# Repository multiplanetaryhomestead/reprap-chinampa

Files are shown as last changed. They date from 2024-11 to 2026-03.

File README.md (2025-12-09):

# RepRap Chinampa

Passive self-watering 3D-printable floating vegetable pot, inspired by the chinampa (floating garden bed).

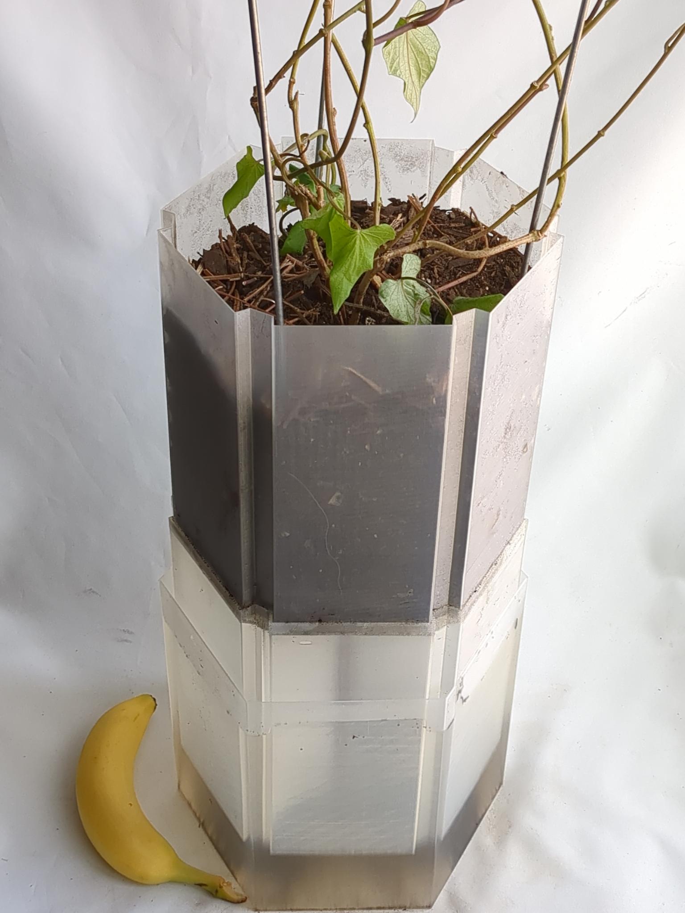
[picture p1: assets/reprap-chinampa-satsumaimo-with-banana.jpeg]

*Full scale model containing satsuma imo (Japanese sweet potato) with banana for scale*

STL files can be downloaded from the [releases](https://github.com/multiplanetaryhomestead/reprap-chinampa/releases/latest) page.

## 3D Printing Notes

### 3D Printer Filament

The models have been successfully printed in Natural PLA

### 3D Printer (Hardware) Configuration/Modifications

The models have been successfully printed on a [Prusa i3 MK3S+](https://help.prusa3d.com/product/mk3s-2) using a [hardened steel 0.4mm nozzle](https://www.printedsolid.com/products/e3d-revo-obxidian-nozzles?variant=40552237400149) and [highv part cooling duct](https://www.printables.com/model/906613-highv-part-cooling-duct-for-prusa-i3-mk3s).

**NOTE**: The standard brass nozzle is **not considered food-safe**, as it wears out. A stainless-steel or titanium nozzle is recommended if you are even considering printing with food in mind.<sup>[1](#footnote1)</sup>

### Print Profile / Slicing

**IMPORTANT**: The STL models should be sliced with **vase mode** enabled in order to produce parts that are airtight and buoyant.<sup>[2](#footnote2)</sup> We recommend slicing with [OrcaSlicer](https://github.com/SoftFever/OrcaSlicer) using the following profile. Note that the profile is for a 0.8 mm nozzle, but have been successfully tested on a 0.4 mm nozzle.

    Nozzle diameter: 0.8 mm nozzle
    Layer height: 0.15 mm
    Wall generator: Classic
    Walls printing order: Inner/Outer
    Bottom shell layers: 5
    Top fill pattern: Aligned Rectilinear
    Bottom fill pattern: Aligned Rectilinear
    Internal solid infill patter: Aligned Rectilinear
    Solid infill direction: 90 degrees
    Infill speed: 5 mm/s
    Solid infill speed: 5 mm/s
    Top solid infill speed: 5 mm/s
    First layer print speed: 5 mm/s
    Max print speed: 5 mm/s
    Overhang speed:
        10%, 25%: 5 mm/s
        25%, 50%: 5 mm/s
        50%, 75%: 5 mm/s
        75%, 100%: 5 mm/s
    Extrusion multiplier: 1.2
    Nozzle temperature:
        First layer: 220 C
        Other layers: 220 C
    Bed temperature:
        First layer: 60 C
        Other layers: 60 C
    Fan speed:
        Min: 100%
        Max: 100%
    Min print speed: 5 mm/s
    Lift height: 0.5 mm
    Retraction height: 2 mm
    Ramping lift: Enabled
    Retraction speed: 50 mm/s

**NOTE**: It is recommended that your first layer is properly calibrated, as to ensure a water-tight print.<sup>[3](#footnote3)</sup>

## Attributions

This project was inspired by the works of

- *Chinampas* pioneered by the native Aztec tribes and farmlands of southwestern region of the Valley of Mexico
- [Self-watering rectangular planter](https://www.printables.com/model/57885-self-watering-rectangular-planter-with-optional-la)
- [Avocado Boat - minimalistic](https://www.printables.com/model/179070-avocado-boat-minimalistic-vase-mode)
- [The RepRap movement](https://reprap.org/)

---
This work is licensed under a [Creative Commons Attribution-ShareAlike 4.0 International License](https://creativecommons.org/licenses/by-sa/4.0/)



<a name="footnote1">1</a>: https://help.prusa3d.com/article/food-safe-fdm-printing_112313

<a name="footnote2">2</a>: https://help.prusa3d.com/article/layers-and-perimeters_1748#spiral-vase

<a name="footnote3">3</a>: https://help.prusa3d.com/article/first-layer-calibration-i3_112364

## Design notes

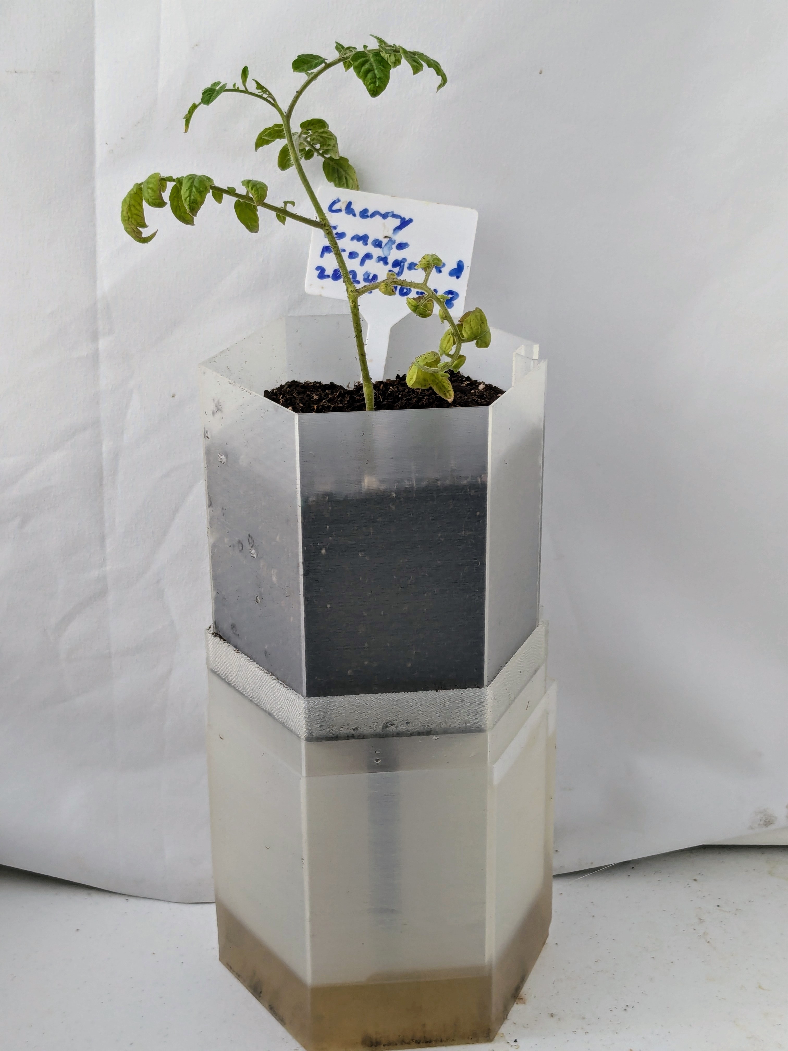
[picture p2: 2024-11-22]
assets/reprap-chinampa-half-scale.jpeg

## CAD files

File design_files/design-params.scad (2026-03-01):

// printer parameters
include <printer-params.scad>

// design parameters
scale_factor = 1.0;

t_wall = d_nozzle;
t_wall_clearance = d_nozzle;

perimeter_buffer = 10;

d_buoy = (2*y_limit/sqrt(3) - perimeter_buffer)*scale_factor;
h_buoy = z_limit*scale_factor;

d_drain_pipe = (y_limit - perimeter_buffer)*scale_factor/5;
h_drain_pipe = 140*scale_factor;

overhang_angle = 60;
d_buoy_cavity = d_buoy-4*t_wall;
h_conical_cavity = tan(90-overhang_angle)*(d_buoy_cavity/2-d_drain_pipe/2);
h_bottom_shell = 6*h_layer;

d_planter = d_buoy_cavity-2*t_wall_clearance;
d_planter_cavity = d_planter-2*t_wall;

d_water_injection_port_cavity_buoy = 20;
d_water_injection_port_buoy = d_water_injection_port_cavity_buoy + 4*t_wall;
x_water_injection_port = d_buoy/2-(d_water_injection_port_cavity_buoy/2)*sin(30)/sin(75);

d_drain_hole=3*d_nozzle;
r_drain_hole_dist = 3*d_drain_hole;
d_wicking_chamber_short_base = d_planter/3;

r_fillet = 2*d_water_injection_port_buoy*scale_factor;
h_bottom_fillet_offset = 0.05*r_fillet;

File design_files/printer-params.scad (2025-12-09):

d_nozzle = 0.8;
h_layer = 0.15;
z_limit = 210;
y_limit = 210;

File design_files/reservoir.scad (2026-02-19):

// design parameters
include <design-params.scad>
use <helper-functions.scad>

t_wall_clearance = 2*d_nozzle;

h_reservoir = z_limit*scale_factor;
d_o = d_buoy+2*t_wall+2*t_wall_clearance;
d_i = d_buoy+2*t_wall_clearance;

// Hidden variables:
res_cyl = 24;
res_fil = 96;
$fn = res_fil;

translate([0, 0, -h_bottom_fillet_offset])
difference() {
    bottomFillet(b=0, r=r_fillet, s=400)
    linear_extrude(h_reservoir+h_bottom_fillet_offset)
    rounding2d(r_fillet)
    hexagon2d(r=d_o/2);

    // remove layers that would otherwise print steep overhangs due to fillet
    linear_extrude(h_bottom_fillet_offset)
    hexagon2d(r=d_o/2);
}

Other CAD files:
design_files/bottomless-planter.scad
design_files/buoy.scad
design_files/drain-mesh.scad
design_files/helper-functions.scad
design_files/planter.scad
design_files/wicking-plate.scad

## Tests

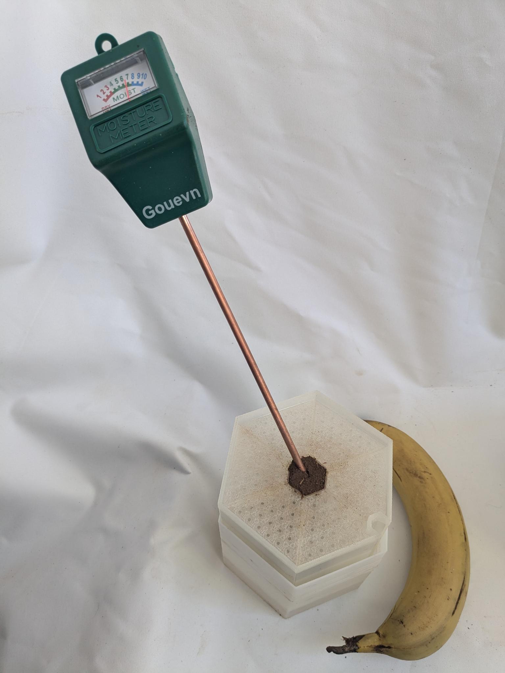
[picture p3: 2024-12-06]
assets/wicking-chamber-moisture-test-half-scale.jpeg

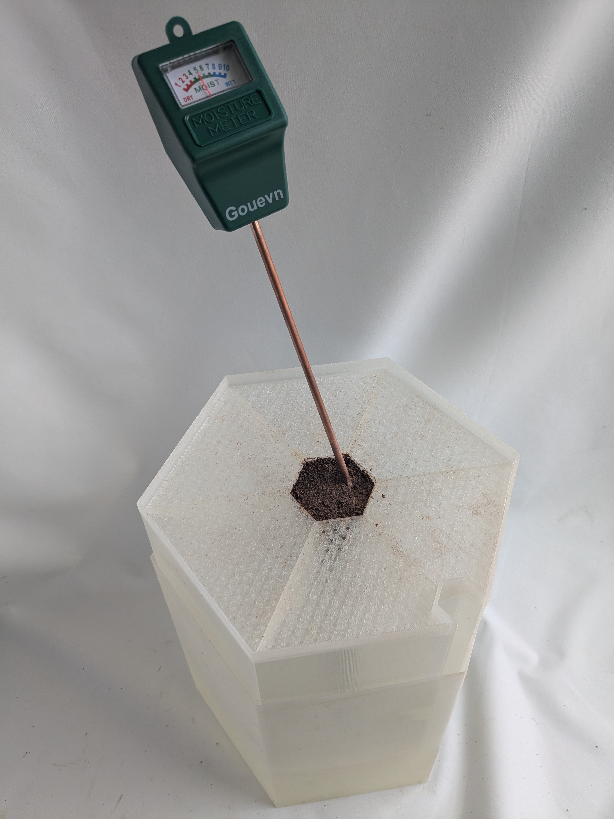
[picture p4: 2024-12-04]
assets/wicking-chamber-moisture-test.jpeg

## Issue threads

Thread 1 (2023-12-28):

add a wicking chamber

capsulecorplab, 2023-12-28:
as current model has insufficient water-wicking

capsulecorplab, 2024-09-27:
closing as per 7b8a93e1d6a42c721dc472023be15c32478ff67c

Closed 2024-09-27.

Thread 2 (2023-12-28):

add STL's

capsulecorplab, 2023-12-28:
for ease of slicing for 3D printing

capsulecorplab, 2023-12-30:
closed as per https://github.com/capsulecorplab/potato-boat/commit/715ee0738dc02bd15ecfe0b02bb1039b3e394630

Closed 2023-12-30.

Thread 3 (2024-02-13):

redesign raft as to accommodate wicking chamber

capsulecorplab, 2024-02-13:
redesign raft as to accommodate wicking chamber (see #1) while providing enough buoyancy to allow for proper drainage from inner shell

capsulecorplab, 2024-09-27:
closing, as raft and inner shell have been merged into "planter", thus is a duplicate of https://github.com/multiplanetaryhomestead/reprap-chinampa/issues/5

Closed 2024-09-27.

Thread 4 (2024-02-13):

add STL slicing notes

capsulecorplab, 2024-02-13:
as to provide sufficient slicing profile for water-tight prints

capsulecorplab, 2024-09-27:
closed as per https://github.com/multiplanetaryhomestead/reprap-chinampa/pull/11/commits/6534f22d3b828c0cdd2c0425062b1be34c0435ba

Closed 2024-09-27.

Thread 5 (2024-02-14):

redesign planter as to allow space for wicking medium

capsulecorplab, 2024-02-14:
redesign inner shell as to accommodate wicking chamber (see https://github.com/capsulecorplab/potato-boat/issues/1)

Closed 2024-10-22.

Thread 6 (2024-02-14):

rename project to `reprap-chinampa`

capsulecorplab, 2024-02-14:
As to better describe its functional purpose; a floating vegetable garden that can be used to produce edible crops, as well as cultivating a source of PLA bio-plastic for 3D printer filament for producing more of itself - inspired by the original concepts of the RepRap movement.

capsulecorplab, 2024-09-27:
closed as per https://github.com/multiplanetaryhomestead/reprap-chinampa/pull/11/commits/610081b1528dc8a10dc42fb8ebf313866afe59ef

Closed 2024-09-27.

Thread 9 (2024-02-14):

add a handle to reservoir

capsulecorplab, 2024-02-14:
allowing for portability with one hand, akin to a bucket

capsulecorplab, 2024-11-26:
Closing as is virtually impossible without reducing water-level capacity and challenges of printing in vase mode.

capsulecorplab, 2024-12-06:
Re-opening, but updating issue title to better reflect requirements

Closed 2024-12-06.

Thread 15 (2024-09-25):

add notes for hardware modifications

capsulecorplab, 2024-09-25:
i.e., fan shroud mod on Mk3S+, used to enhance part cooling for printing watertight prints with 45 deg overhangs

## references
- https://www.printables.com/model/906613-highv-part-cooling-duct-for-prusa-i3-mk3s

capsulecorplab, 2024-09-27:
closed as per https://github.com/multiplanetaryhomestead/reprap-chinampa/pull/11/commits/6534f22d3b828c0cdd2c0425062b1be34c0435ba

Closed 2024-09-27.

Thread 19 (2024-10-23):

Print still occasionally crashing along xy on first 3 layers

capsulecorplab, 2024-10-23:
as of #11

Closed 2024-10-28.

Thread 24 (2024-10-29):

maximize planter volume available for soil medium to utilize full Prusa i3 build volume

capsulecorplab, 2024-10-29:
as to be able to grow bigger vegetables (s.a., potatoes) without sacrificing buoyancy, wicking capability, and aeration/drainage. Volume available for grow medium is constrained by the build volume of a Prusa i3-style printer minus clearances for skirts and wall thicknesses. Planter should perhaps be split into 2 parts as to maximize available grow medium volume, while also retaining sufficient buoyancy

Closed 2024-11-22.

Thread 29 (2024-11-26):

improve wicking capacity

capsulecorplab, 2024-11-26:
wicking capacity seems to be constricted as of [v1.0.0-beta1](https://github.com/multiplanetaryhomestead/reprap-chinampa/releases/tag/v1.0.0-beta1).

NOTE: seems to primarily be of issue at half scale

Closed 2024-12-01.

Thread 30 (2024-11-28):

reduce stringing on first layer and bottom shell

capsulecorplab, 2024-11-28:
as to reduce crashes and improve overall quality of print, particularly on wicking plate as of [v1.0.0-beta1](https://github.com/multiplanetaryhomestead/reprap-chinampa/releases/tag/v1.0.0-beta1)

Closed 2024-12-03.

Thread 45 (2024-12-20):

Redesign to include water injection ports on all corners

capsulecorplab, 2024-12-20:
as it's currently cumbersome to access at a single corner

Closed 2024-12-22.

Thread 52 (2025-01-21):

Slicer generates air gap along overhang on buoy at 0.5 scale (in PrusaSlicer)

capsulecorplab, 2025-01-21:
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

capsulecorplab, 2025-01-28:
Seems to be a PrusaSlicer issue, as air gap artifact doesn't appear when sliced with OrcaSlicer
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

capsulecorplab, 2025-02-05:
Issue persists in PrusaSlicer v2.8.1

capsulecorplab, 2025-02-19:
OBE as of #53

Closed 2025-02-19.

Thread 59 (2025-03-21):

Cracking observed along drain pipe on full scale, as well as half scale, print

capsulecorplab, 2025-03-21:
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

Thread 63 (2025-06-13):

improve wicking capacity for full scale model

capsulecorplab, 2025-06-13:
## suggested fix
set wicking plate base and pipe diameter to be proportional to ~1/4th and ~1/3rd buoy diameter, respectively

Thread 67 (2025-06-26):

Reservoir leaking along overhangs

capsulecorplab, 2025-06-26:
As of #60
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

capsulecorplab, 2025-06-26:
Likely due to user error, as model was not sliced with the recommended 1.2x extrusion multiplier (flow ratio in OrcaSlicer)...

capsulecorplab, 2025-06-27:
Issue no longer persists as of reprint with proper flow ratio and reducing max print speed to 10 mm/s (due to jamming issues at 15 mm/s)
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

Closed 2025-06-27.

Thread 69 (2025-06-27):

3D printer jams when using generic brands of PLA

capsulecorplab, 2025-06-27:
As mentioned in #67, printer jams with generic brands of PLA after adjusting flow ratio to 1.2x; need to update slicing notes to slow down max print speed to 10 mm/s

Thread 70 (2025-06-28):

unexpected bridging at layer between transition from short to long drainpipe on wicking plate

capsulecorplab, 2025-06-28:
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

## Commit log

2023-12-25 add CAD model for outer shell
    [potato_boat_outer_shell.scad]
2023-12-25 add CAD model for inner shell
    [potato_boat_inner_shell.scad]
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2024-02-14 fix cavity radius for inner & outer shell
    should be half bucket diameter minus wall thickness
    [potato_boat_inner_shell.scad, potato_boat_outer_shell.scad]
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2024-02-14 increase hole cutout in inner shell to 50.8mm
    [potato_boat_inner_shell.scad]
2024-02-17 create wicking chamber for 50mm peat moss pellet
    based on parametric net pot design by leemes https://www.thingiverse.com/thing:790339 licensed under CC-BY-SA 3.0 https://creativecommons.org/licenses/by-sa/3.0/
    [wicking-chamber.scad]
2024-02-17 redesign raft to accommodate wicking chamber
    [potato_boat_raft.scad]
2024-02-17 create shape to be sliced for drain mesh
    [drainage_mesh.scad]
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2024-04-10 resize raft height to provide enough buoyancy while requiring less than 1kg of filament using 0.8mm nozzle w/ 15% lightening infill
    [raft.scad]
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2024-06-28 add draft scad model for printing raft in vasemode
    currently scaled to 20% for testing
    TODO: needs to be refactored to use include statement https://github.com/openscad/openscad/issues/605#issuecomment-32962394
    [raft.scad]
2024-06-29 increase raft ht to 200mm. decrease keyhole clearance to 0.8mm
    [raft.scad]
2024-06-30 replace drain mesh with wicking chamber funnel
    [drainage_mesh.scad, wicking-chamber-funnel.scad]
2024-06-30 increase overhang angle to 70 deg for improved vasemode printing
    [raft.scad]
2024-08-13 update top layers in funnel to be 6x layer height
    [wicking-chamber-funnel.scad]
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2024-09-25 reshape buoy (base & funnel) componets to be hexagonal
    [buoy-base.scad, buoy-funnel.scad]
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2024-09-26 decrease wall clearance to 0.1mm in reservoir
    [reservoir.scad]
2024-09-26 refactor planter & reservoir to use shared config files
    - create `printer-params.scad` & `design-params.scad`
    - use "include <printer-params.scad>" in `planter.scad` & `reservoir.scad` (see https://github.com/openscad/openscad/issues/605#issuecomment-32962394)
    - increase planter diameter in `design-params.scad` to be parametrically scaled to y-axis limit
    - decrease wicking chamber height to half (expanded) peat moss pellet
    - increase top hexagonal cavity by half (expanded) peat moss pellet
    - increase drainpipe to 2x nozzle diameter
    [design-params.scad, planter.scad, printer-params.scad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]
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2024-09-27 use custom wall thickness for planter & reservoir
    [design-params.scad, planter.scad, reservoir.scad]
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2024-09-27 remove wicking chamber
    OBE as planter already contains a cavity for wicking material
    [wicking-chamber.scad]
2024-09-27 increase drainpipe in planter to 4x nozzle diameter
    [planter.scad]
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2024-10-03 redesign to reduce buoyancy at full scale
    [design-params.scad, planter.scad]
2024-10-04 set reservoir wall clearance to nozzle diameter
    [reservoir.scad]
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2024-10-04 increase reservoir wall clearance to 2x nozzle diameter
    [reservoir.scad]
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2024-10-22 improve drainage
    - remove conical section of wicking chamber
    - convert bottom layers directly below wicking chamber into a drain mesh
    [planter.scad]
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2024-10-25 add wicking-plate for improved aeration
    - add wicking plate for holding wicking medium and creates air gap for better aeration of roots via perforated mesh
    - refactor planter.scad to be able to share wicking chamber parameters across models
    - create helper-functions.scad file for importing helper functions
    [design-params.scad, helper-functions.scad, planter.scad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]
2024-10-25 maximize volume available for soil/grow medium
    - lower conical section to base of planter
    - change wicking chamber height of wicking plate to height of conical section
    - refactor drain mesh generators to use for-loop while increasing perforation size
    [design-params.scad, planter.scad, wicking-plate.scad]
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2024-10-26 update slicing notes to mitigate crashes
    - Specify Infill, Solid infiill, and Top solid infill speed of 5 mm/s
    - Reduce first layer speed to 5 mm/s
    - Reduce extrusion multiplier to 0.2
    - Specify lift height of 0.8 mm
2024-10-27 apply 45 deg chamfer to edges of wicking plate
    [wicking-plate.scad]
2024-10-31 separate planter into bottomless planter + buoy
    - replace planter.scad w/ bottomless-planter.scad & buoy.scad
    - redesign water injection port
    - refactor global variables and helper functions
    - redesign wicking plate (with support beams) to accommodate planter redesign
    [bottomless-planter-.scad, buoy.scad, design-params.scad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]
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2024-11-02 WIP attempt to increase buoyancy
    - temporarily set scale_factor to 0.2
    - increase overhang angle to 60 deg
    - decrease wicking chamber diameter to 20 mm
    - increase wicking chamber diameter to 120 mm
    - implement new drain mesh in buoy using experimental honeycomb generator
    - fix rendering issues with water injection port at small scale
    [buoy.scad, design-params.scad, helper-functions.scad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]
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2024-11-02 fix water injection port to properly render in bottomless-planter at small scale
    - temporarily set scale factor to 0.5
    - refactor h_buoy to be global variable
    - fix water_injection_port() function in buoy to render properly at small scales
    [bottomless-planter.scad, buoy.scad, design-params.scad]
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2024-11-03 redesign wicking plate for improved fit into buoy
    - replace old drain mesh function w/ honeycomb generator
    - add wall clearance to base to allow for clearance fit with buoy
    - adjust chamfer to account for 60 deg overhang
    - add cavity for water injection port
    [helper-functions.scad, wicking-plate.scad]
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2024-11-03 refactor buoy & wicking plate to use same drain mesh geometry
    [buoy.scad, design-params.scad, wicking-plate.scad]
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2024-11-04 rename wicking_chamber variables to drain_pipe
    as it's currently used to model the drain pipe
    [buoy.scad, design-params.scad, wicking-plate.scad]
2024-11-04 redesign wicking plate w/ conical tip
    as to remove the need for drain mesh geometry in buoy
    [wicking-plate.scad]
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2024-11-04 fix issue w/ scale factor shifting drain mesh in wicking plate
    [wicking-plate.scad]
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2024-11-19 increase surface area contact between wicking medium and grow medium
    increases diameter of wicking chamber base to 1/5th planter diameter (~50 mm at full scale)
    [wicking-plate.scad]
2024-11-20 lower lift height to 0.6 mm in slicing notes
    as to reduce stringing without crashing
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2024-11-29 attempt to improve wicking capacity and reduce print time
    - increase volume of wicking chamber while maintaining clearance w/ drain pipe
    - increase surface area contact between wicking medium and soil/grow medium to 1/4th planter diameter
    - add perforations at conical tip by rotating conical tip
    - reduce print time by increasing distance between drain mesh holes
    [design-params.scad, wicking-plate.scad]
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2024-12-05 set drain pipe diameter to be a constant value
    as to be unaffected by scale factor as fix for wicking issues at half-scale
    [design-params.scad]
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2024-12-19 WIP redesign for water injection ports on all corners
    [bottomless-planter.scad, buoy.scad, design-params.scad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]
2024-12-22 reduce wall clearnce along water injection port on wicking plate & planter
    [bottomless-planter.scad, wicking-plate.scad]
2024-12-24 fix for gap along water injection port on planter at full scale
    [bottomless-planter.scad]
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2025-01-04 redesign planter to mitigate soil spillage
    - rename bottomless-planter to planter
    - include perforated base for drainage with cavity for wicking chamber
    - fix clearance issues along water injection port
    [design-params.scad, planter.scad]
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2025-01-27 Reduce stringing and print time of drain mesh
    Replaces honeycomb_generator() with isometric gred (60 deg rotated rectilinear grids at each bottom layer height)
    [helper-functions.scad, planter.scad]
2025-01-27 refactor drain mesh to use isometric_grid_generator() helper function + add brim to inner wall
    [helper-functions.scad, planter.scad]
2025-02-05 fix unintended cut along water injection port walls
    [helper-functions.scad]
2025-02-05 set water injection port diameter to equal drain pipe diameter
    - refactor water injection port to use more DRY code
    - use global variable for translating water injection port distance on all models
    - move invisible_shell() module into helper-functions.scad
    [buoy.scad, design-params.scad, helper-functions.scad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]
2025-02-06 hot fix for mitigating cracking along drain pipe on bottom of buoy
    [buoy.scad]
2025-02-09 refactor h_conical_cavity to be a function of d_buoy_cavity
    [design-params.scad]
2025-02-12 adjust support beams to sit flush against buoy overhangs
    [wicking-plate.scad]
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2025-03-23 transform conical cutout at bottom of drainpipe on buoy from a hexagon to a circle in attempt to patch cracking
    [buoy.scad]
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2025-03-30 convert base of buoy to circular edge in attempt to patch cracking along water injection port
    [buoy.scad]
2025-04-04 add chamfer on keyhole cutout along bottom of buoy
    [buoy.scad, helper-functions.scad]
2025-06-14 Replace chamfer w/ fillet along bottom of buoy
    [buoy.scad, design-params.scad, helper-functions.scad]
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2025-06-15 resolve slicer cantilever warning
    [design-params.scad]
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2025-06-17 attempt to resolve weak layer adhesion at vasemode transition
    [buoy.scad, design-params.scad]
2025-06-19 adjust bottom fillet overhangs to be ~45 degrees
    [buoy.scad, helper-functions.scad]
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2025-06-21 refactor buoy & reservoir with variable resolution
    as to allow quick rendering for design iteration purposes
    [buoy.scad, helper-functions.scad, reservoir.scad]
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2025-06-22 refactor d_drain_pipe t/b 1/5th short diagonal of buoy
    [design-params.scad]
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2025-09-12 convert wicking chamber from hexagonal to circular cross-section
    [wicking-plate.scad]
2025-09-22 fix issue with bottom shell not rendering for short wicking chamber base
    [wicking-plate.scad]
2025-09-23 increase resolution along conical cavity in attempt to fix shifting layer lines along conical wall on buoy
    [buoy.scad]
2025-09-23 circularize wicking chamber interface to accommodate wicking plate redesign
    [planter.scad]
2025-09-23 refactor isometric_grid_generator & rectilinear_grid_generator to support parameter for hole diameter
    [helper-functions.scad]
2025-09-23 set mesh hole diameter to 1.5x nozzle diameter
    [planter.scad]
2025-09-23 fix rectilinear_grid_generator() to be able to accept n parameter
    [helper-functions.scad]
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2025-11-06 attempt to fix leaks by reducing layer height to 0.15 mm & max print speed to 5 mm/s
    [printer-params.scad]
2025-11-07 remove GCode Post-Processing notes, as post-processing script doesn't appear to affect vasemode prints
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2025-11-16 fix resolution for rendering correct number of sides on reservoir
    [reservoir.scad]
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2025-11-22 replace planter w/ bottomless-planter
    [bottomless-planter.scad]
2025-11-22 increase bottom shell from 3 to 6 layers
    as to improve structural support on drain mesh
    [design-params.scad]
2025-12-10 add drainage holes to tip of wicking plate
    [wicking-plate.scad]
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2026-02-09 replace circular bottom fillet w/ default fillet on reservoir
    - replace call to circular_outer_bottom_fillet() with bottomFillet()
    - include scale_factor in r_fillet
    - set h_bottom_fillet_offset to 0.05*r_fillet
    [design-params.scad, reservoir.scad]
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2026-02-16 apply fillets to wall edges of reservoir
    - adds hexagon2d() and rounding2d() to helper-functions
    - refactors hexagon generation to use hexagon2d() function
    - applies rounding2d() to newly refactor hexagon for filleting wall edges of reservoir
    [helper-functions.scad, reservoir.scad]
2026-02-23 increase hole diameter of drain mesh to 2x nozzle diameter
    [drain-mesh.scad]
2026-02-23 increase diameter of inner rim as to avoid rectilinear infill in sliced model
    [drain-mesh.scad]

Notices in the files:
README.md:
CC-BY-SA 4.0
